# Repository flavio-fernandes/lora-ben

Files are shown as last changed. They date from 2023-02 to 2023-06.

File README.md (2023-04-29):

# lora-ben

#### CircuitPython based project for reading distance sensor and advertise it via lora

This project uses [lora](https://learn.adafruit.com/radio-featherwing/circuitpython-for-rfm9x-lora) to periodically send
temperature and distance sensor values.
Since the unit will be kept outdoors, it has a Lithium Ion Polymer Battery with a solar panel. 
In order to conserve energy, it uses [deep sleep](https://learn.adafruit.com/deep-sleep-with-circuitpython) and a relay that
cuts power to the sensors while doing so.

Components on the **Sensor** side:
- [Large Ultrasonic (Sonar) Sensor with Horn and UART Output](https://www.adafruit.com/product/4664)
- [DS18B20 Digital temperature sensor](https://www.adafruit.com/product/374)
- [Adafruit LoRa Radio FeatherWing - RFM95W 900 MHz - RadioFruit](https://www.adafruit.com/product/3231)
- [Adafruit Universal USB / DC / Solar Lithium Ion/Polymer charger - bq24074](https://www.adafruit.com/product/4755)
- [6V 2W Solar Panel - ETFE - Voltaic P126](https://www.adafruit.com/product/5366)
- [3.8 / 1.3mm or 3.5 / 1.1mm to 5.5 / 2.1mm DC Jack Adapter Cable](https://www.adafruit.com/product/2788)
- [Lithium Ion Polymer Battery - 3.7v 2500mAh](https://www.adafruit.com/product/328)
- [Adafruit Non-Latching Mini Relay](https://www.adafruit.com/product/2895) **OR** [Low Signal Relay](https://www.mouser.com/ProductDetail/Panasonic-Industrial-Devices/HY1-4.5V?qs=YINDDaGsG3FSnYZykcV2vQ%3D%3D)
- [Push button](https://www.adafruit.com/product/1445)
- [Adafruit Feather RP2040](https://www.adafruit.com/product/4884) -- or any feather capable of running Circuit Python!

Components on the **Receiver** side:
- [Adafruit LoRa Radio Bonnet with OLED - RFM95W @ 915MHz - RadioFruit](https://www.adafruit.com/product/4074)
- [Raspberry Pi Zero W](https://www.adafruit.com/product/3708) -- or any other Raspberry Pi

lora-ben

You can see more [pictures of this project here :art:](https://flic.kr/s/aHBqjAtpNE).

## 3d print STL files

lora-ben-enclosure

[See here](3d-print.md) for info on [.STL files](https://github.com/flavio-fernandes/lora-ben/tree/main/stl) used to print the enclosure, as well as the additional parts.

#### Adafruit Show and Tell

Adafruit offers guides along with products that make it easy to build this project.
JP and Erin hosted [Show and Tell](https://www.youtube.com/c/adafruit/videos) on March 22nd, 2023 and
I had the honor of [talking about what I did so far](https://www.youtube.com/watch?v=m7rZJALOhrc&t=999s) to them.

lora-ben talk (https://www.youtube.com/watch?v=m7rZJALOhrc&t=999s)
    
# Installation

## Sensor (sender) Side

### Install CircuitPython

See [CircuitPython Downloads](https://circuitpython.org/downloads?q=rp2040) and follow the steps documented there for the board you are using.

### Remove _all_ files from CIRCUITPY drive

```
# NOTE: Do not do this before backing up all files!!!
>>> import storage ; storage.erase_filesystem()
```

**NOTE:** The deep sleep interval can be adjusted by modifying the [const.py file](https://github.com/flavio-fernandes/lora-ben/blob/main/const.py). This may be a good time to tweak it. :smiley:

### Copying files from cloned repo to CIRCUITPY drive
```
# First, get to the REPL prompt so the board will not auto-restart as
# you copy files into it

# Assuming that CircuitPython board is mounted under /Volumes/CIRCUITPY
$  cd ${THIS_REPO_DIR}
$  [ -e ./code.py ] && \
   [ -d /Volumes/CIRCUITPY/ ] && \
   rm -rf /Volumes/CIRCUITPY/*.py && \
   (tar czf - *.py) | ( cd /Volumes/CIRCUITPY ; tar xzvf - ) && \
   echo ok || echo not_okay
```

### Libraries

Use [circup](https://learn.adafruit.com/keep-your-circuitpython-libraries-on-devices-up-to-date-with-circup)
to install these libraries:

```text
$ python3 -m venv .env && source ./.env/bin/activate && \
  pip install --upgrade pip

$ pip3 install circup

$ for LIB in \
    adafruit_ds18x20 \
    adafruit_rfm9x \
    ; do circup install $LIB ; done
```

This is what it should look like:
```text
$ ls /Volumes/CIRCUITPY/
boot_out.txt	code.py		const.py	lib		lora.py		main.py		settings.toml	sonar.py	temperature.py

$ ls /Volumes/CIRCUITPY/lib
adafruit_bus_device	adafruit_ds18x20.mpy	adafruit_onewire	adafruit_rfm9x.mpy

$ cat /Volumes/CIRCUITPY/boot_out.txt
Adafruit CircuitPython 8.0.3 on 2023-02-23; Adafruit Feather RP2040 with rp2040
Board ID:adafruit_feather_rp2040
UID:...

$ circup freeze | sort
Found device at /Volumes/CIRCUITPY, running CircuitPython 8.0.3.
adafruit_bus_device==5.2.3
adafruit_ds18x20==1.3.16
adafruit_onewire==2.0.4
adafruit_rfm9x==2.2.13
```

At this point, all needed files should be in place and all that is needed is to let
code.py run. From the Circuit Python serial console:

```text
>>  <CTRL-D>
soft reboot
...
```

## Receiver Side

### Install bonnet on Raspberry Pi as [documented here](https://learn.adafruit.com/adafruit-radio-bonnets)

```bash
# update packages
sudo apt-get update && sudo apt-get -y upgrade && sudo apt-get -y dist-upgrade && echo ok

# enable spi and i2c
sudo raspi-config   ;  # select interface-options --> spi and i2c

# install pip3
sudo apt install -y python3-pip git

# clone this repo
$ git clone https://github.com/flavio-fernandes/lora-ben.git

# install needed python dependencies
$ cd lora-ben/rpi && 
  sudo pip3 install -r requirements.txt && \
  echo ok
```

At this point, try running this script to display received packets:

```bash
$ ./basic_receive.py
```

### Using MQTT broker

If there is an MQTT broker you can use, follow these steps in order to publish
the packets received via lora:

```bash
$ vi ./rpi_const.py  ; # edit broker info and anything else

$ vi ./bin/loraben.service  ; # make sure path to start_loraben.sh in this file is proper
 
$ sudo cp -v ./bin/loraben.service /lib/systemd/system/

$ sudo systemctl enable --now loraben.service  ; # start and enable the service

# to Check if all is well, you can try these commanda
$ ./bin/tail_log.sh

$ systemctl status loraben

$ sudo systemctl restart loraben
```

The following commands can be used as a reference for subscribing to the MQTT topics

```bash
# Use this topic to force a refresh on all the topics, instead of waiting for periodic updates
$ mosquitto_pub -i pub_cli -h mqtt  -t "loraben/ping" -n

# Subscribing to loraben, assuming you did not change the prefix in rpi_const.py as mentioned above
$ mosquitto_sub -F '@Y-@m-@dT@H:@M:@S@z : %q : %t : %p' -h mqtt  -t "loraben/#"
2023-02-25T17:50:43-0500 : 0 : loraben/ping :
2023-02-25T17:50:47-0500 : 0 : loraben/msg : {'ip': '192.168.30.217', 'id': '217', 'batt': '4.0864 v', 'temp': '62.6 F', 'dist': '385 mm', 'rssi': '-76 dB', 'ts': '25/02/2023 17:33:57', 'len': '51 bytes'}
2023-02-25T17:50:51-0500 : 0 : loraben/ip : 192.168.30.217
2023-02-25T17:50:55-0500 : 0 : loraben/id : 217
2023-02-25T17:50:59-0500 : 0 : loraben/batt : 4.0864 v
2023-02-25T17:51:03-0500 : 0 : loraben/temp : 62.6 F
2023-02-25T17:51:07-0500 : 0 : loraben/dist : 385 mm
2023-02-25T17:51:11-0500 : 0 : loraben/rssi : -76 dB
2023-02-25T17:51:15-0500 : 0 : loraben/ts : 25/02/2023 17:33:57
2023-02-25T17:51:19-0500 : 0 : loraben/len : 51 bytes

```

## Open MQTT Gateway

[See here](open-mqtt-gateway.md) for info on using an ESP32 with Lora hardware to easily bridge Lora messages into MQTT.

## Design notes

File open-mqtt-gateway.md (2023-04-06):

# Using Open MQTT Gateway to parse Lora-Ben Messages

Using [OpenMQTTGateway](https://docs.openmqttgateway.com/) on a LILYGO card
bought at [AliExpress](https://www.aliexpress.us/item/2251832685763835.html?gatewayAdapt=bra2usa4itemAdapt&_randl_shipto=US)
or at [Amazon](https://a.co/d/dw0PhZ6).

```
LILYGO® TTGO LoRa32 V2.1_1.6 Version 915Mhz
ESP32 LoRa OLED 0.96 Inch SD Card Bluetooth WIFI Wireless Module ESP-32 SMA
SX1276 915MHz CH9102, China
```

Use this [youtube video as a reference](https://youtu.be/_gdXR1uklaY?t=110).
I am able to load the image `ttgo-lora32-v1-915` directly from the Chrome browser. Be aware that
this image does not take advantage of the OLED in this board, but its ease to use makes up
for that limitation. For a codebase that gives more control over the board, consider using
the [Xinyuan-LilyGO/LilyGo-LoRa-Series](https://github.com/Xinyuan-LilyGO/LilyGo-LoRa-Series.git) repo (see below).

**NOTE:** One caveat I hit when using the Mac OSX, was the need for installing the correct serial driver:

If you are on macOS and have a LilyGo LoRa32 V2.1 board, make sure you have the correct driver for the
[CH9102 Serial Chip installed](https://github.com/WCHSoftGroup/ch34xser_macos)
and selected in the popup when initiating the web install. To finalise
the driver installation don't forget the confirmation in the Security section of System Preferences after the restart.
The correct driver to then select in the popup of this web install is `/dev/cu.wchusbserialXXXXXXXXXXX`

After loading the firmware, [follow the steps described](https://docs.openmqttgateway.com/upload/portal.html)
in the OpenMQTTGateway site, so it can connect to an MQTT broker, and the desired MQTT topic.

This is what the payload will look like from the gateway:
    
```
{"rssi":-50,"snr":9.75,"pferror":-2189,"packetSize":49,"hex":"FF01000069643A35362C20626174743A332E363820762C2074656D703A36342E3420462C20646973743A31323137206D6D"}
```

To parse it, use the script as shown:

```bash
$ sudo apt install -y jq xxd
 
$ MQTT_BROKER=mqtt ; \
  PREFIX=lora/ESP32_LORA/LORAtoMQTT

$ mosquitto_sub -h $MQTT_BROKER -t ${PREFIX} | jq
{
  "rssi": -48,
  "snr": 9.5,
  "pferror": -3414,
  "packetSize": 50,
  "hex": "FF01000069643A3135362C20626174743A332E363820762C2074656D703A36362E3220462C20646973743A32383334206D6D"
}

$ mosquitto_sub -h $MQTT_BROKER -t ${PREFIX} | jq '.hex'
"FF01000069643A36302C20626174743A332E3638333220762C2074656D703A36362E3220462C20646973743A33303231206D6D"

$ while : ; do \
  mosquitto_sub -h $MQTT_BROKER -t ${PREFIX} -C 1 | jq --unbuffered '.hex' | xxd -r -p
  done
id:173, batt:3.6736 v, temp:66.2 F, dist:281 mm

$ while : ; do \
  MSG=$(mosquitto_sub -h $MQTT_BROKER -t ${PREFIX} -C 1 | jq --unbuffered '.hex' | xxd -r -p)
  MSG_ASCII="${MSG//[^[:ascii:]]/}"
  echo ${MSG_ASCII}
  DIST=$(echo ${MSG_ASCII} | cut -d, -f4 | cut -d' ' -f2 | cut -d: -f2)
  echo "Distance: ${DIST}"
  done
id:224, batt:3.68 v, temp:67.1 F, dist:271 mm
Distance: 271
```

## [Xinyuan-LilyGO / LilyGo-LoRa-Series](https://github.com/Xinyuan-LilyGO/LilyGo-LoRa-Series)

Tweaks in order to build LilyGo-LoRa-Series for this board via VScode:
    
```
$ cd LilyGo-LoRa-Series.git/

$ git rev-parse HEAD
fe64bb0ddfb3f46b284e694b55be23af9a23431f

$ git remote -v
origin  https://github.com/Xinyuan-LilyGO/LilyGo-LoRa-Series.git (fetch)
origin  https://github.com/Xinyuan-LilyGO/LilyGo-LoRa-Series.git (push)

$ git diff
diff --git a/examples/ArduinoLoRa/LoRaReceiver/utilities.h b/examples/ArduinoLoRa/LoRaReceiver/utilities.h
index c85dc3a..7f8a884 100644
--- a/examples/ArduinoLoRa/LoRaReceiver/utilities.h
+++ b/examples/ArduinoLoRa/LoRaReceiver/utilities.h
@@ -19,7 +19,8 @@
 * Option: 433E6,470E6,868E6,915E6
 * */

-#define LoRa_frequency      433E6
+#define LoRa_frequency      915E6

 #define UNUSE_PIN                   (0)
diff --git a/platformio.ini b/platformio.ini
index 32bf2ce..9e7aacf 100644
--- a/platformio.ini
+++ b/platformio.ini
@@ -22,15 +22,15 @@
 [platformio]
 ; default_envs = t3-v1.0
 ; default_envs = t3-v1.3
-; default_envs = t3-v1.6
+default_envs = t3-v1.6
 ; default_envs = t3-v1.8
 ; default_envs = t3-v2.0
 ; default_envs = t-beam-v0.7
 ; default_envs = t-beam-v1.x
-default_envs = t-beam-s3-core
+; default_envs = t-beam-s3-core
 ; default_envs = t3-s3-v1.0

-; src_dir = examples/ArduinoLoRa/LoRaReceiver
+src_dir = examples/ArduinoLoRa/LoRaReceiver
 ; src_dir = examples/ArduinoLoRa/LoRaSender
 ; src_dir = examples/GPS/UBlox_BasicNMEARead
 ; src_dir = examples/GPS/UBlox_NMEAParsing
@@ -94,12 +94,13 @@ monitor_filters =
        esp32_exception_decoder

-monitor_port = COM178
-upload_port  = COM178
+monitor_port = /dev/cu.wchusbserial56440061481
+upload_port  = /dev/tty.wchusbserial56440061481

 build_flags =
     ;define radio frequency
-    -DLoRa_frequency=868
+    ; -DLoRa_frequency=915E6

[esp32dev_base]
```

```
diff --git a/examples/ArduinoLoRa/LoRaReceiver/LoRaReceiver.ino b/examples/ArduinoLoRa/LoRaReceiver/LoRaReceiver.ino
index cd4101a..37701c1 100644
--- a/examples/ArduinoLoRa/LoRaReceiver/LoRaReceiver.ino
+++ b/examples/ArduinoLoRa/LoRaReceiver/LoRaReceiver.ino
@@ -26,12 +26,22 @@ void loop()
         Serial.print("Received packet '");

         String recv = "";
+        String recv2 = "";
+        int i;
         // read packet
         while (LoRa.available()) {
-            recv += (char)LoRa.read();
+            i = LoRa.read();
+            if (i > 31 && i < 128) {
+                if (recv.length() <= 24) {
+                    recv += (char)i;
+                } else {
+                    recv2 += (char)i;
+                }
+            }
         }

         Serial.println(recv);
+        Serial.println(recv2);

         // print RSSI of packet
         Serial.print("' with RSSI ");
@@ -40,12 +50,10 @@ void loop()
         if (u8g2) {
             u8g2->clearBuffer();
             char buf[256];
-            u8g2->drawStr(0, 12, "Received OK!");
-            u8g2->drawStr(0, 26, recv.c_str());
-            snprintf(buf, sizeof(buf), "RSSI:%i", LoRa.packetRssi());
-            u8g2->drawStr(0, 40, buf);
-            snprintf(buf, sizeof(buf), "SNR:%.1f", LoRa.packetSnr());
-            u8g2->drawStr(0, 56, buf);
+            u8g2->drawStr(0, 18, recv.c_str());
+            u8g2->drawStr(0, 33, recv2.c_str());
+            snprintf(buf, sizeof(buf), "RSSI:%i    SNR:%.1f", LoRa.packetRssi(), LoRa.packetSnr());
+            u8g2->drawStr(0, 60, buf);
             u8g2->sendBuffer();
         }
 #endif
```

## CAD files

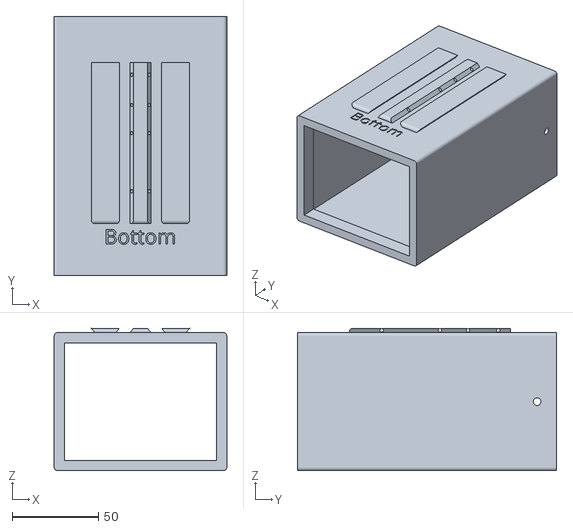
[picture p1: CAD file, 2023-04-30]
stl/6of9_main_enclosure.stl
100.0 x 150.0 x 82.5

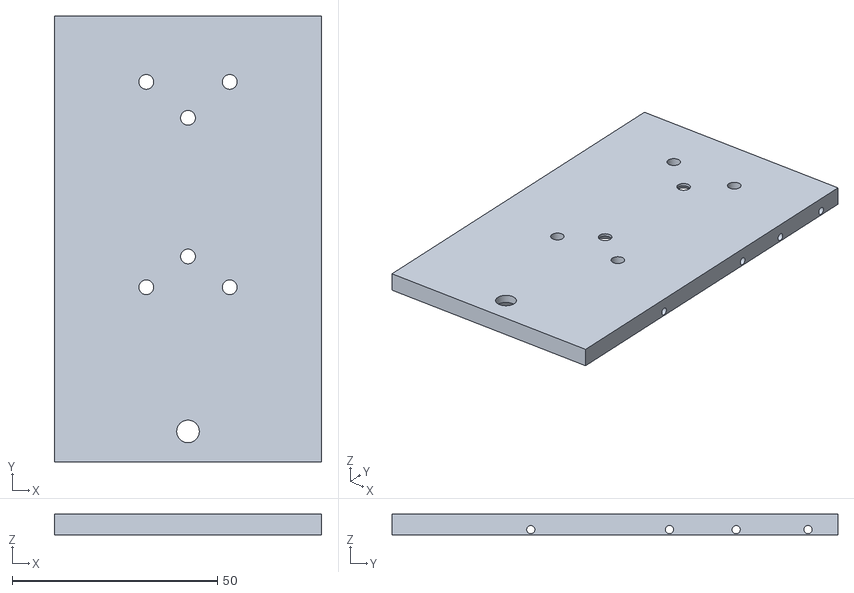
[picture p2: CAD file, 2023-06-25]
stl/4of9_bracket_on_tree.stl
65.0 x 108.5 x 5.00

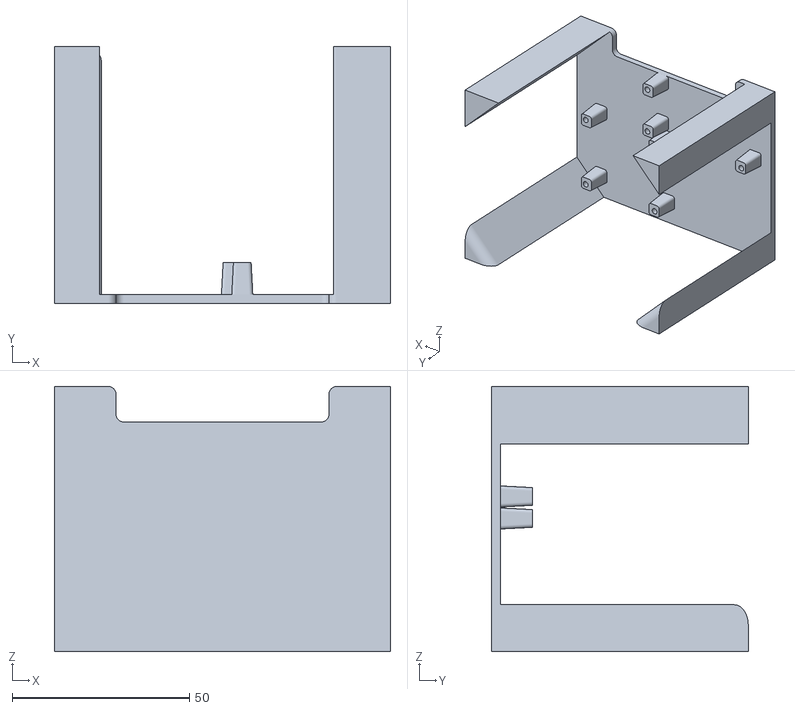
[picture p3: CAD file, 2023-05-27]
stl/5of9_feather_plate.stl
94.7 x 72.3 x 74.7

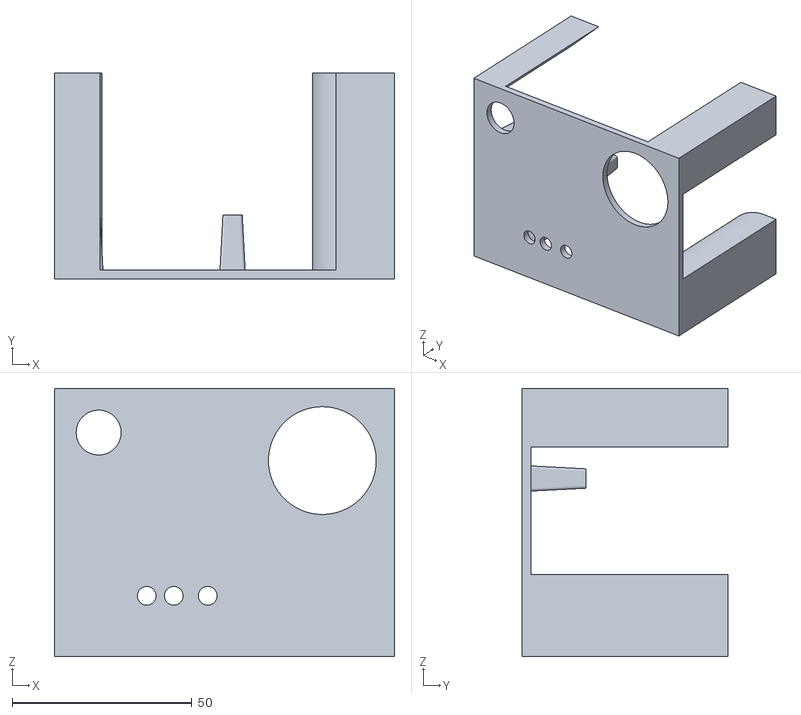
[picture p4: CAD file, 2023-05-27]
stl/3of9_bottom_plate.stl
94.7 x 57.5 x 74.7

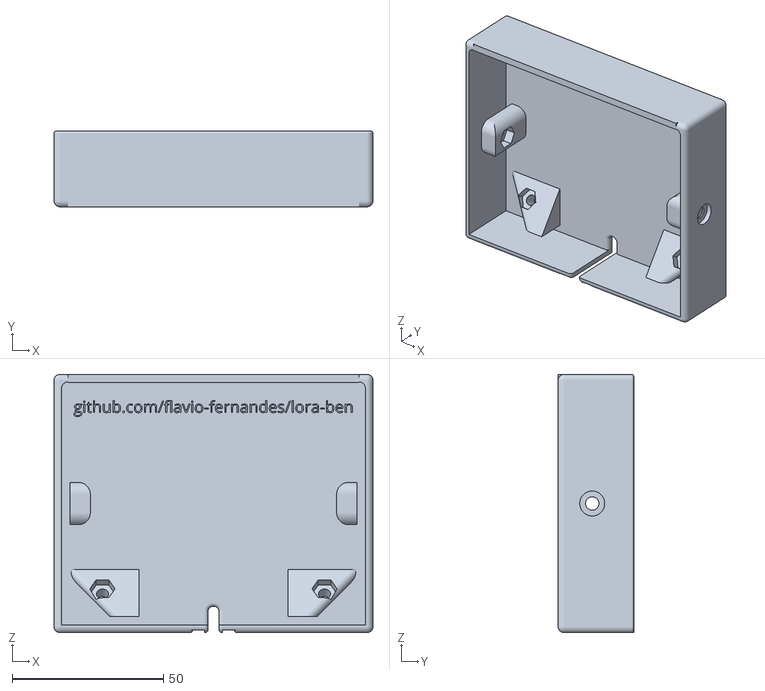
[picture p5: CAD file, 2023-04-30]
stl/9of9_top_plate.stl
105.3 x 25.0 x 85.3

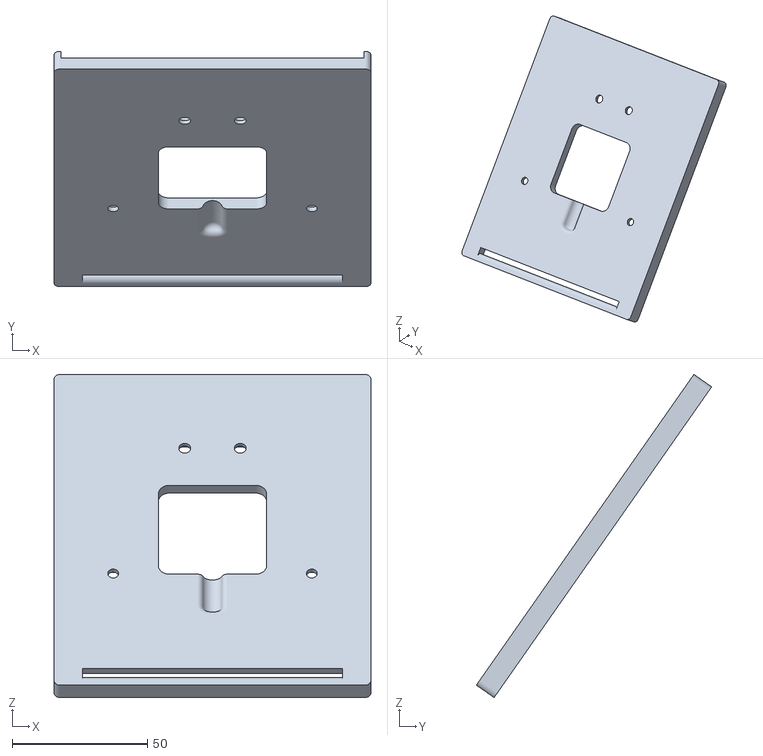
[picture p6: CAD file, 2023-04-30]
stl/7of9_solar_harness.stl
117.0 x 86.9 x 119.3

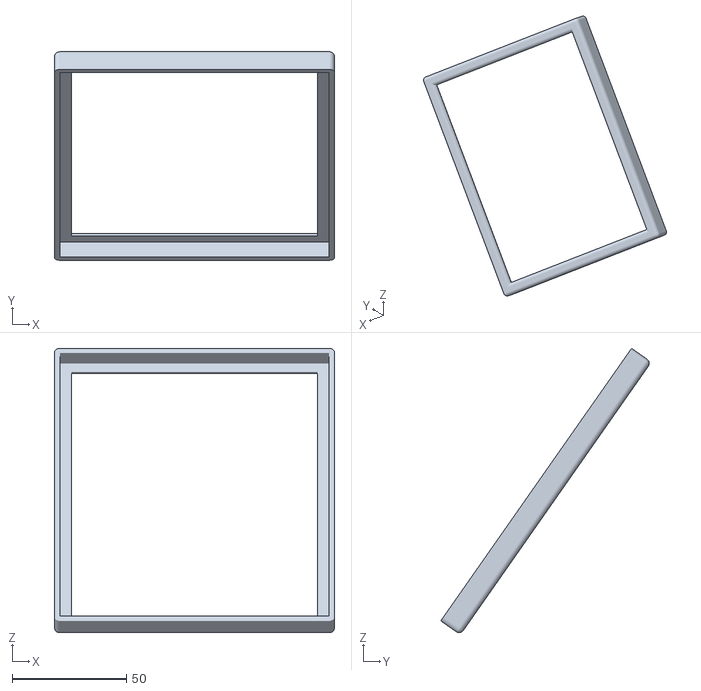
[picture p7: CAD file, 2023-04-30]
stl/2of9_bezel.stl
122.3 x 91.1 x 124.2

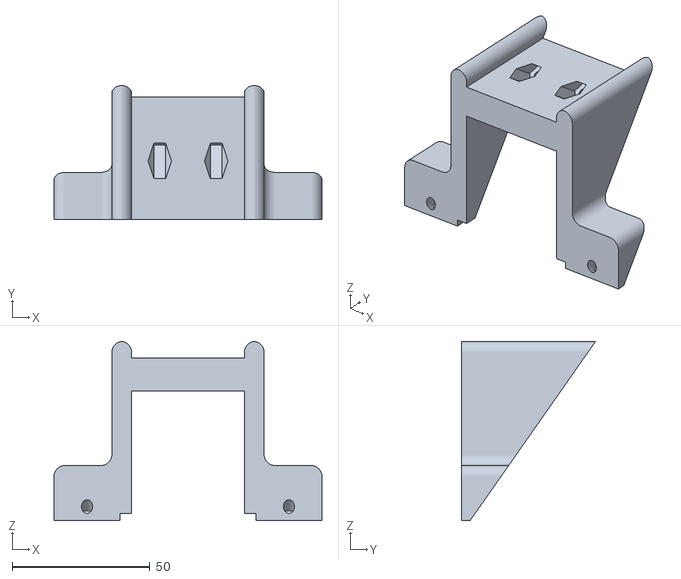
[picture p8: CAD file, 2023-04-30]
stl/8of9_solar_stand.stl
97.3 x 48.7 x 65.1

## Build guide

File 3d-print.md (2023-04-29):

# Lora-Ben Enclosure

The enclosure was build using [this OnShape project](https://cad.onshape.com/documents/43c4b1c9e8ea9284b97b9423/w/821148c53625e112d50571c1/e/f13fb274aa1dd264db38a6c0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). Special thanks to [Evan](https://youtu.be/yWPM9o08TuM) for making the [captive nut feature](https://bit.ly/CaptiveNutFeature).

The exported STL files [are available here](https://github.com/flavio-fernandes/lora-ben/tree/main/stl). They were broken into 9 parts, which can be printed individually.

lora-ben-onshape
        
You can see more [pictures of this project here :art:](https://flic.kr/s/aHBqjAtpNE).
    
## Nuts and bolts

* 8 x M2.5 x 8mm [Screws](https://www.adafruit.com/product/3299)

* 6 x M4 [Nuts](https://a.co/d/0XM04Cd)

* 2 x M4 x 12mm [Screws](https://a.co/d/0XM04Cd)

* 2 x M4 x 16mm [Screws](https://a.co/d/0XM04Cd)

* 2 x M4 x 20mm [Screws](https://a.co/d/0XM04Cd)

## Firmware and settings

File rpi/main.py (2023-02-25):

#!/usr/bin/env python
import asyncio
import collections
from contextlib import AsyncExitStack

from asyncio_mqtt import Client, MqttError

from rpi import rpi_const as const
from rpi import log
from rpi.events import MqttMsgEvent
from rpi.basic_receive import (
    basic_receive_main,
    get_latest,
    stop_basic_receive,
)
from rpi.mqtt import (
    handle_mqtt_publish,
    handle_mqtt_messages,
)


async def handle_main_event_mqtt(mqtt_msg: MqttMsgEvent, mqtt_send_q: asyncio.Queue):
    if mqtt_msg.topic in const.SUB_TOPICS:
        msg = f"Mqtt event received {mqtt_msg.topic} {mqtt_msg.payload}"
        logger.info(msg)
        if mqtt_msg.topic.endswith("/ping"):
            curr_values = get_latest()
            await publish_values(curr_values, curr_values, mqtt_send_q)
        return

    msg = f"Ignoring Mqtt event received {mqtt_msg.topic} {mqtt_msg.payload}"
    logger.debug(msg)


async def handle_main_events(mqtt_send_q: asyncio.Queue, main_events_q: asyncio.Queue):
    handlers = {
        "MqttMsgEvent": handle_main_event_mqtt,
    }
    while not stop_gracefully:
        main_event = await main_events_q.get()
        logger.debug(f"Handling {main_event.event}...")
        handler = handlers.get(main_event.event)
        if handler:
            await handler(main_event, mqtt_send_q)
        else:
            logger.error(f"No handler found for {main_event.event}")
        main_events_q.task_done()


async def cancel_tasks(tasks):
    logger.info("Cancelling all tasks")
    for task in tasks:
        if task.done():
            continue
        task.cancel()
        try:
            await task
        except asyncio.CancelledError:
            pass


async def publish_values(curr_values, delta_values, mqtt_send_q: asyncio.Queue):
    logger.info(
        f"publishing {const.TOPIC_PUB_MSG}:{curr_values} and sub-topics {sorted(delta_values.keys())}"
    )

    await mqtt_send_q.put(
        MqttMsgEvent(topic=const.TOPIC_PUB_MSG, payload=f"{curr_values}")
    )
    for topic, payload in delta_values.items():
        await mqtt_send_q.put(
            MqttMsgEvent(topic=f"{const.TOPIC_PREFIX}{topic}", payload=f"{payload}")
        )


async def monitor_latest_receive(mqtt_send_q: asyncio.Queue):
    prev_values = {}
    while not stop_gracefully:
        await asyncio.sleep(1)
        curr_values = get_latest()

        if prev_values == curr_values:
            continue

        prev_set = set(prev_values.items())
        curr_set = set(curr_values.items())
        await publish_values(curr_values, dict(curr_set - prev_set), mqtt_send_q)
        prev_values = curr_values.copy()


async def main_loop():
    global stop_gracefully

    # https://pypi.org/project/asyncio-mqtt/
    logger.debug("Starting main event processing loop")
    mqtt_broker_ip = const.MQTT_BROKER_IP
    mqtt_username = const.MQTT_BROKER_USERNAME
    mqtt_password = const.MQTT_BROKER_PASSWORD
    mqtt_client_id = const.MQTT_CLIENT_ID
    mqtt_send_q = asyncio.Queue(maxsize=256)
    main_events_q = asyncio.Queue(maxsize=256)

    async with AsyncExitStack() as stack:
        # Keep track of the asyncio tasks that we create, so that
        # we can cancel them on exit
        tasks = set()
        stack.push_async_callback(cancel_tasks, tasks)

        client = Client(
            mqtt_broker_ip,
            username=mqtt_username,
            password=mqtt_password,
            client_id=mqtt_client_id,
        )
        await stack.enter_async_context(client)

        messages = await stack.enter_async_context(client.messages())
        task = asyncio.create_task(handle_mqtt_messages(messages, main_events_q))
        tasks.add(task)

        task = asyncio.create_task(handle_mqtt_publish(client, mqtt_send_q))
        tasks.add(task)

        for topic in const.SUB_TOPICS:
            await client.subscribe(topic)

        task = asyncio.create_task(handle_main_events(mqtt_send_q, main_events_q))
        tasks.add(task)

        quiet = not (const.LOG_TO_CONSOLE and const.LOG_LEVEL_DEBUG)
        task = asyncio.create_task(basic_receive_main(quiet=quiet))
        tasks.add(task)

        task = asyncio.create_task(monitor_latest_receive(mqtt_send_q))
        tasks.add(task)

        # Wait for everything to complete (or fail due to, e.g., network errors)
        await asyncio.gather(*tasks)

    logger.debug("all done!")


# cfg_globals
stop_gracefully = False
logger = None


async def main():
    global stop_gracefully

    # Run the loop indefinitely. Reconnect automatically if the connection is lost.
    reconnect_interval = const.MQTT_RECONNECT_INTERVAL
    while not stop_gracefully:
        try:
            await main_loop()
        except MqttError as error:
            logger.warning(
                f'MQTT error "{error}". Reconnecting in {reconnect_interval} seconds.'
            )
        except (KeyboardInterrupt, SystemExit):
            logger.info("got KeyboardInterrupt")
            stop_gracefully = True
            stop_basic_receive()
            break
        await asyncio.sleep(reconnect_interval)


if __name__ == "__main__":
    logger = log.getLogger()
    log.initLogger()

    if const.LOG_TO_CONSOLE:
        log.log_to_console()
    if const.LOG_LEVEL_DEBUG:
        log.set_log_level_debug()

    logger.info("main process started")
    asyncio.run(main())
    if not stop_gracefully:
        raise RuntimeError("main is exiting")

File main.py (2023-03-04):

import alarm
import time
import board
import analogio
import digitalio
import random

from const import deep_sleep_interval, send_packets
from lora import send_report
from sonar import read_sonar
from temperature import read_temperature


def done(bump_sequenace, msg):
    global sequence, relay, blue_led, yellow_led

    blue_led.value, yellow_led.value, relay.value = False, False, False

    time_alarm = alarm.time.TimeAlarm(
        monotonic_time=time.monotonic() + deep_sleep_interval
    )

    if bump_sequenace:
        try:
            alarm.sleep_memory[0] = (sequence + send_packets) % 256
        except (NotImplementedError, IndexError):
            # https://github.com/adafruit/circuitpython/issues/5081
            pass

    print(f"Sleeping {deep_sleep_interval} seconds. {msg}")
    alarm.exit_and_deep_sleep_until_alarms(time_alarm)


# Initialize message id with random in case sleep_memory is
# not available.
sequence = random.randint(0, 255 - send_packets)
try:
    if alarm.wake_alarm:
        sequence = alarm.sleep_memory[0]
    else:
        time.sleep(3)
except (NotImplementedError, IndexError):
    # https://github.com/adafruit/circuitpython/issues/5081
    pass

# The replay controls power to all the gizmos attached.
# Because of that, we must "power it up" before trying to use them!
relay = digitalio.DigitalInOut(board.D9)
relay.direction = digitalio.Direction.OUTPUT
relay.value = True

# give woken up sensors a few seconds to quiesce
time.sleep(2)

blue_led = digitalio.DigitalInOut(board.D5)
blue_led.direction = digitalio.Direction.OUTPUT

yellow_led = digitalio.DigitalInOut(board.D25)
yellow_led.direction = digitalio.Direction.OUTPUT

# STATE 1: SENSORS POWERED UP
blue_led.value, yellow_led.value = False, False

# Battery value is obtained by using a 10k resistor divider
# https://learn.adafruit.com/adafruit-feather-rp2040-pico?view=all#measuring-battery-3122383
# https://learn.sparkfun.com/tutorials/voltage-dividers/all
battery = analogio.AnalogIn(board.A2)
battery_value = battery.value / 10000

temperature = read_temperature()
if not temperature:
    done(False, "failed to read temperature")

# STATE 2: GOT BATTERY AND TEMPERATURE
blue_led.value, yellow_led.value = True, False
time.sleep(1)

distance = read_sonar()
if not distance:
    print("failed to read distance:{distance}. Sensor farther than 4 meters?")
    distance = -1
    # done(False, "failed to read distance")
else:
    # STATE 3: GOT BATTERY, TEMPERATURE AND DISTANCE
    blue_led.value, yellow_led.value = False, True
    time.sleep(1)

send_fails = 0
for i in range(send_packets):
    if not send_report(sequence + i, battery_value, temperature, distance):
        send_fails += 1
    time.sleep(1)

if send_fails:
    done(False, "failed to send report")

# STATE 4: SENT RADIO REPORT
blue_led.value, yellow_led.value = True, True

time.sleep(3)
done(True, "")

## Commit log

2023-03-04 tweaks
    - Moved sonar uart rx from D13 to A3
    - Collect more samples to make sonar values more reliable
    - Send 3 lora advertisements per loop, instead of 1
2023-04-29 Add doc on 3d print parts
2023-05-27 stls: minor tweak to pillars
    Adding a 3-degree draft to the pillars of the circuit boards for a
    stronger base.
    [3of9_bottom_plate.stl, 5of9_feather_plate.stl]
2023-06-25 stls: simplify bracket_on_tree part
    [4of9_bracket_on_tree.stl]
